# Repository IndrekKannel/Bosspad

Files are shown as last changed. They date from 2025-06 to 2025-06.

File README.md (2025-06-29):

# Bosspad  

I designed a 9 key and 1 encoder macropad for the real bosses. It also has an OLED screen and is designed to be mouted on a vertical surface.  
I plan on using it as a button box for sim racing. 
It uses QMK firmware and supports VIA


## PCB

I designed the PCB with KiCad




## Case

I designed the case in Fusion360 and it can be printed in 2 parts.  
It is assembled with 4 M3x16 screws and 4 M3x5x4mm heatset inserts.



## BOM

### PCB

- 1x Seeed Studio Xiao RP2040
- 1x EC11E Rotary Encoder (switch built in)
- 1x rotary Encoder Knob (can also be printed)
- 1x 0.91" SSD1306 OLED screen
- 9x Cherry MX style switches
- 9x Blank DSA keycaps
- 10x DO-35 diodes (THT)

### Case

- 4x M3x16mm socket head bolts
- 4x M3x5x4mm heatset inserts
- bosspad_top.step
- bosspad_bottom.step

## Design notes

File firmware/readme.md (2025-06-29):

# bosspad

Boss looking macropad

* Keyboard Maintainer: [Indrek Iannel](https://github.com/indrekkannel)
* Hardware Supported: Seeed studio XIAO RP2040
* Hardware Availability: -

See the [build environment setup](https://docs.qmk.fm/#/getting_started_build_tools) and the [make instructions](https://docs.qmk.fm/#/getting_started_make_guide) for more information. Brand new to QMK? Start with our [Complete Newbs Guide](https://docs.qmk.fm/#/newbs).

## Bootloader

Enter the bootloader in 3 ways:

* **Bootmagic reset**: Hold down the key at (0,0) in the matrix (usually the top left key or Escape) and plug in the keyboard
* **Physical reset button**: Briefly press the button on the back of the PCB - some may have pads you must short instead
* **Keycode in layout**: Press the key mapped to `QK_BOOT` if it is available

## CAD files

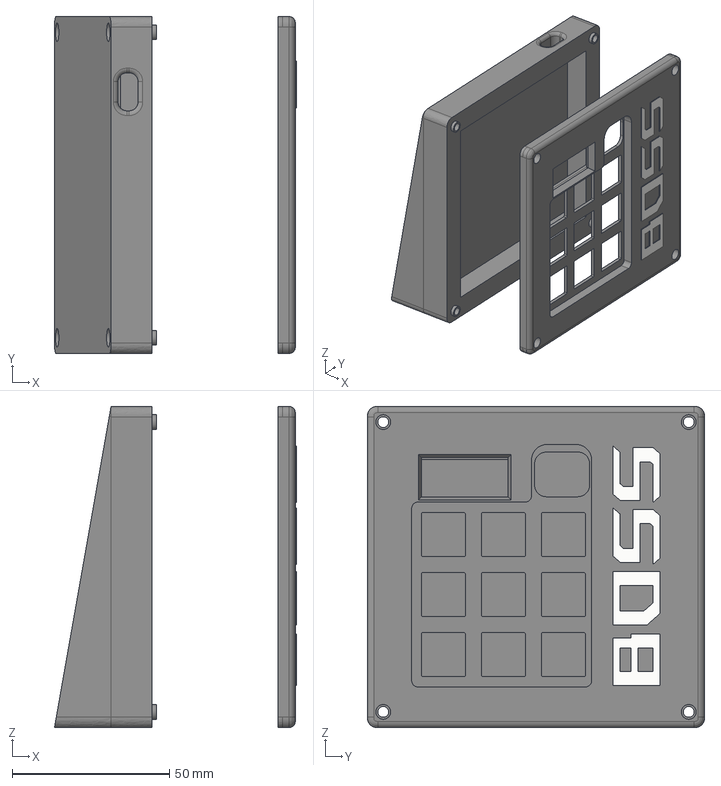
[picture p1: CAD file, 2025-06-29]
cad/bosspad_complete.step
76.9 x 107.0 x 102.0 mm
Macro bottom
macro top

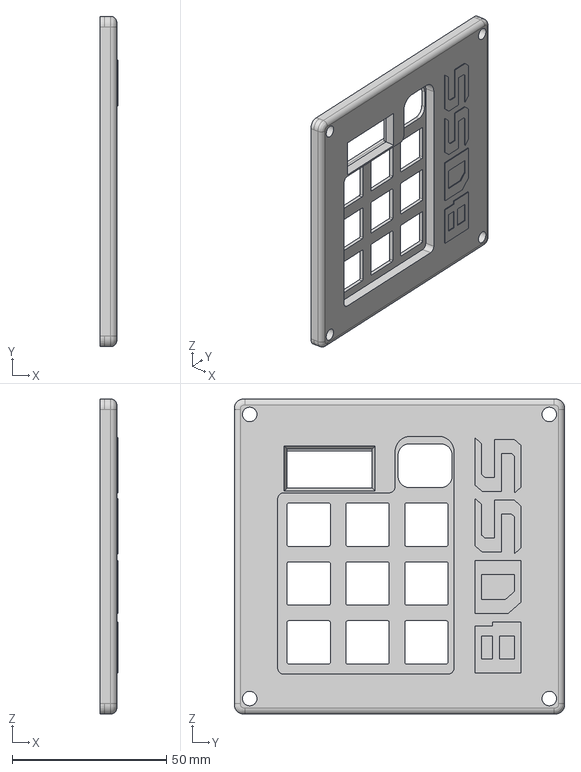
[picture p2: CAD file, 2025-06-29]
production/bosspad_top.step
5.90 x 107.0 x 102.0 mm

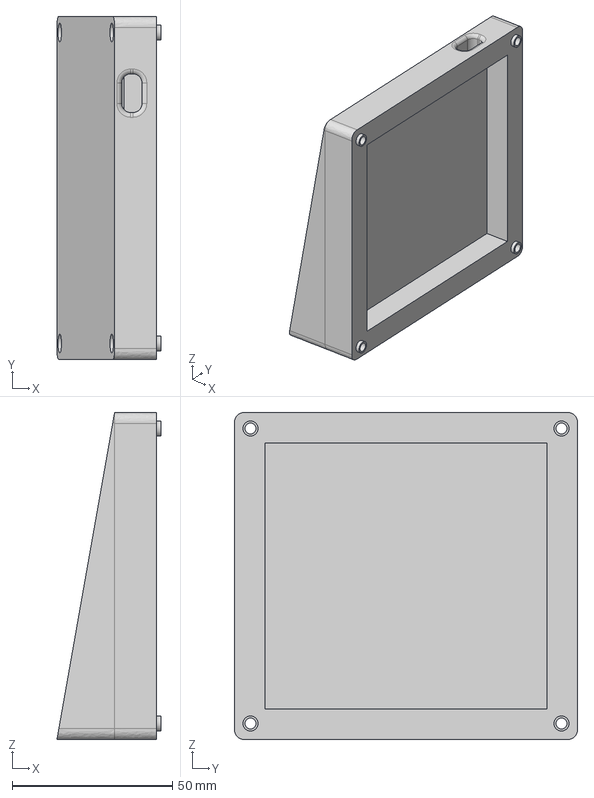
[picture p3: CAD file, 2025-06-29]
cad/bosspad_bottom.step
32.5 x 107.0 x 102.0 mm

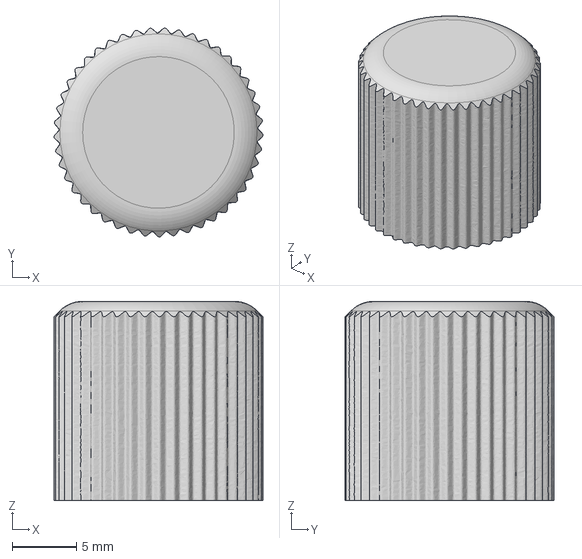
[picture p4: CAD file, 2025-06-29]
production/encoder_knob.step
16.3 x 16.2 x 15.5 mm

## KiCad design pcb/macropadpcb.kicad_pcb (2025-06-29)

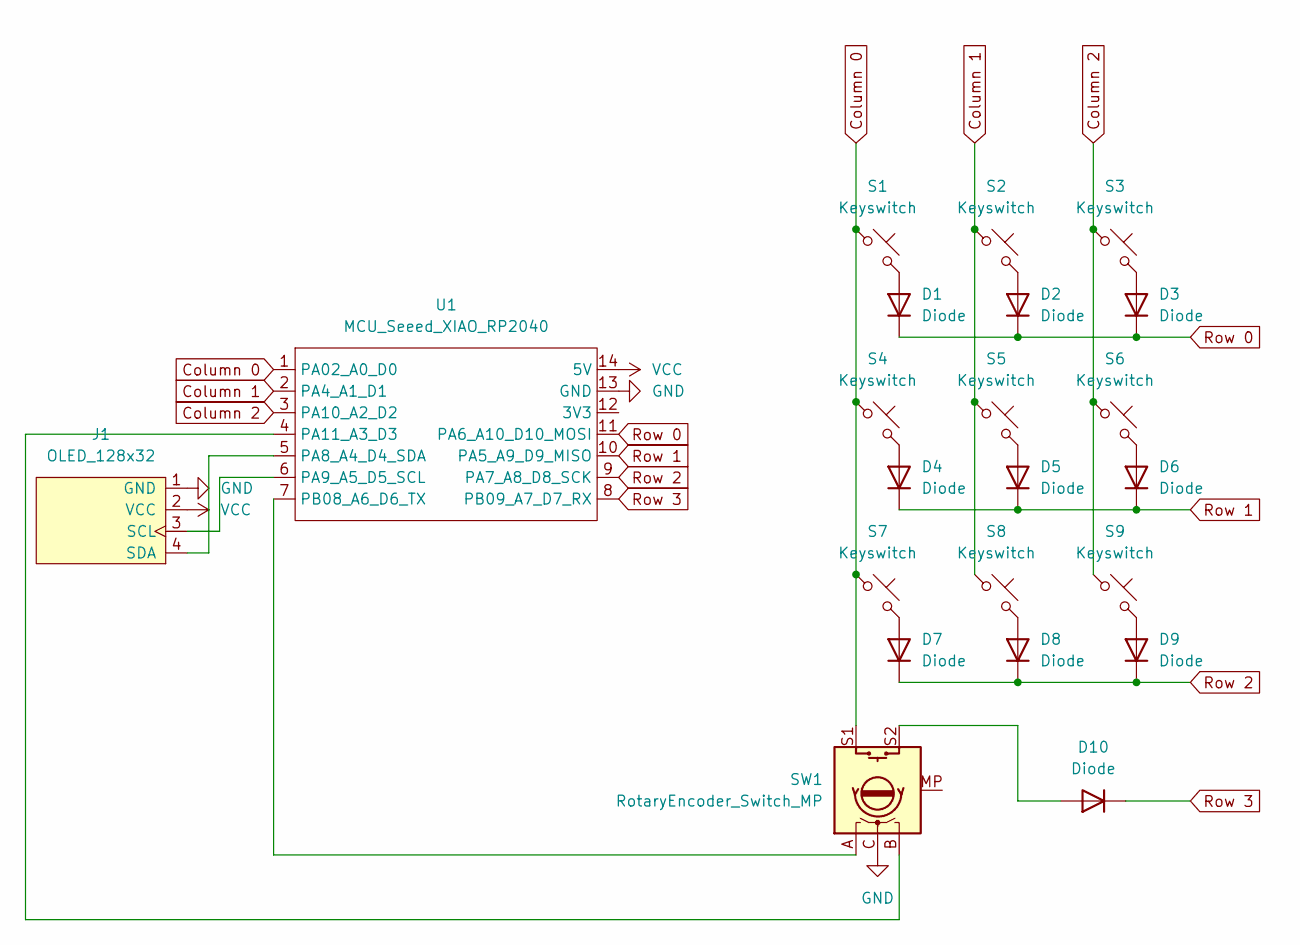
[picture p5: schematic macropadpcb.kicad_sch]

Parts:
D1, D2, D3, D4, D5, D6, D7, D8, D9, D10: Diode; Diode_DO-35
J1: OLED_128x32
S1, S2, S3, S4, S5, S6, S7, S8, S9: Keyswitch; MX_PCB_1.00u
SW1: RotaryEncoder_Switch_MP; RotaryEncoder_Alps_EC11E-Switch_Vertical_H20mm_MountingHoles
U1: MCU_Seeed_XIAO_RP2040; Seeed_XIAO_RP2040

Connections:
Column 0: S1.1, S4.1, S7.1, SW1.S1, U1.1 (PA02_A0_D0)
Column 1: S2.1, S5.1, S8.1, U1.2 (PA4_A1_D1)
Column 2: S3.1, S6.1, S9.1, U1.3 (PA10_A2_D2)
GND: J1.1 (GND), SW1.C, U1.13 (GND)
unnamed: D1.2 (A), S1.2
unnamed: D2.2 (A), S2.2
unnamed: D3.2 (A), S3.2
unnamed: D4.2 (A), S4.2
unnamed: D5.2 (A), S5.2
unnamed: D6.2 (A), S6.2
unnamed: D7.2 (A), S7.2
unnamed: D8.2 (A), S8.2
unnamed: D9.2 (A), S9.2
unnamed: D10.2 (A), SW1.S2
unnamed: J1.3 (SCL), U1.6 (PA9_A5_D5_SCL)
unnamed: J1.4 (SDA), U1.5 (PA8_A4_D4_SDA)
unnamed: SW1.B, U1.4 (PA11_A3_D3)
unnamed: SW1.A, U1.7 (PB08_A6_D6_TX)
Row 0: D1.1 (K), D2.1 (K), D3.1 (K), U1.11 (PA6_A10_D10_MOSI)
Row 1: D4.1 (K), D5.1 (K), D6.1 (K), U1.10 (PA5_A9_D9_MISO)
Row 2: D7.1 (K), D8.1 (K), D9.1 (K), U1.9 (PA7_A8_D8_SCK)
Row 3: D10.1 (K), U1.8 (PB09_A7_D7_RX)
VCC: J1.2 (VCC), U1.14 (5V)

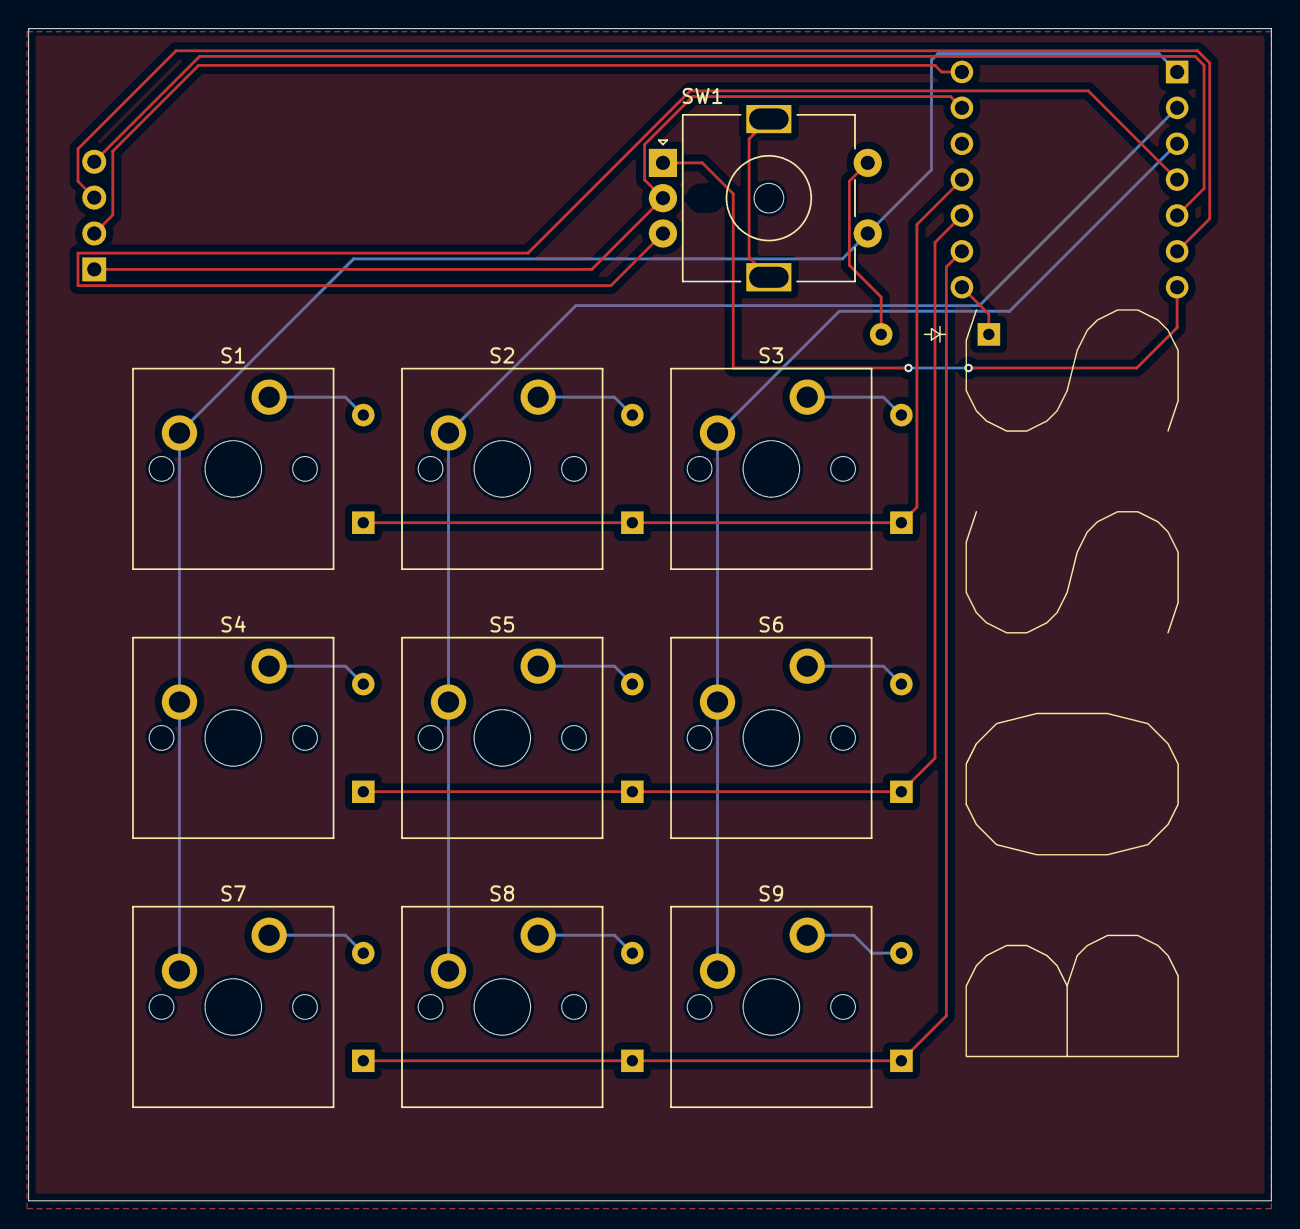
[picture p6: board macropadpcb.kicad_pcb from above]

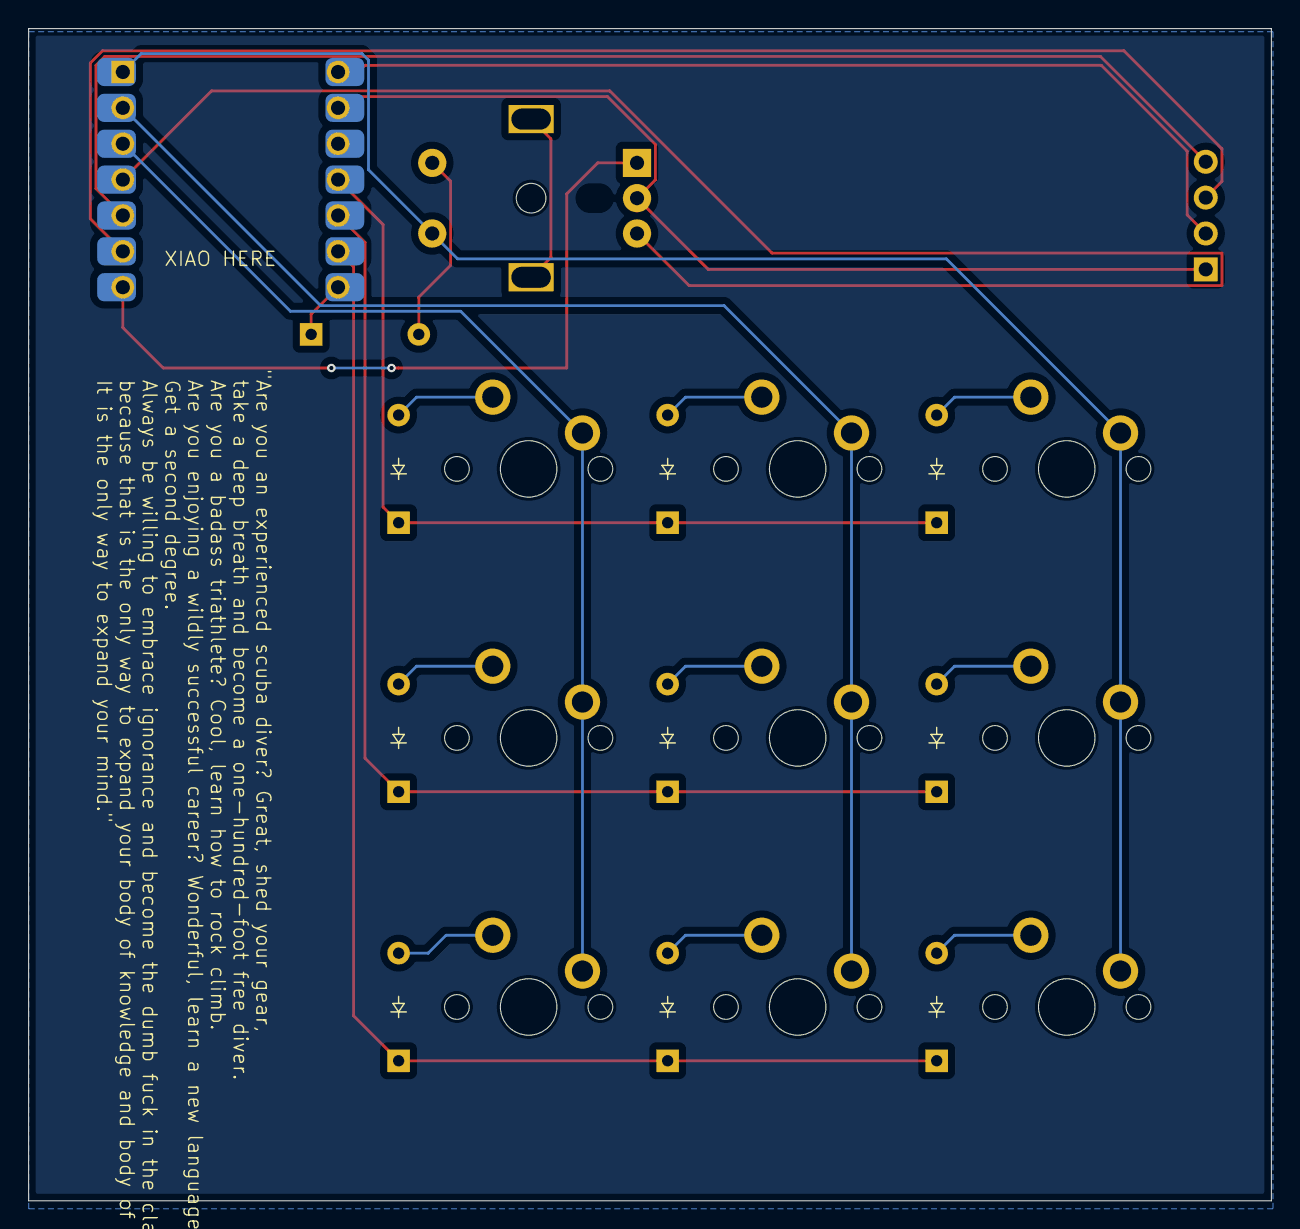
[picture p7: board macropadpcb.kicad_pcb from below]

Board: 2 copper layers, 88.0 x 83.0 mm, 22 parts (10 on the bottom side), 23 nets.

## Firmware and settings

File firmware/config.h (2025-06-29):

#define ENCODER_A_PINS { GP0 }
#define ENCODER_B_PINS { GP29 }
#define NUM_ENCODERS 1
#define I2C_DRIVER I2CD1
#define I2C1_SDA_PIN GP6
#define I2C1_SCL_PIN GP7

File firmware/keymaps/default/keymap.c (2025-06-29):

// Copyright 2023 QMK
// SPDX-License-Identifier: GPL-2.0-or-later

#include QMK_KEYBOARD_H

const uint16_t PROGMEM keymaps[][MATRIX_ROWS][MATRIX_COLS] = {
    /*
     * ┌───┬───┬───┬───┐
     * │ 7 │ 8 │ 9 │ / │
     * ├───┼───┼───┼───┤
     * │ 4 │ 5 │ 6 │ * │
     * ├───┼───┼───┼───┤
     * │ 1 │ 2 │ 3 │ - │
     * ├───┼───┼───┼───┤
     * │ 0 │ . │Ent│ + │
     * └───┴───┴───┴───┘
     */
    [0] = LAYOUT(
        KC_P7,   KC_P8,   KC_P9,   
        KC_P4,   KC_P5,   KC_P6,   
        KC_P1,   KC_P2,   KC_P3,   
        KC_MPLY
    ),
    [1] = LAYOUT(
        KC_P7,   KC_P8,   KC_P9,   
        KC_P4,   KC_P5,   KC_P6,   
        KC_P1,   KC_P2,   KC_P3,   
        KC_MPLY
    ),
    [2] = LAYOUT(
        KC_P7,   KC_P8,   KC_P9,   
        KC_P4,   KC_P5,   KC_P6,   
        KC_P1,   KC_P2,   KC_P3,   
        KC_MPLY
    ),
    [3] = LAYOUT(
        KC_P7,   KC_P8,   KC_P9,   
        KC_P4,   KC_P5,   KC_P6,   
        KC_P1,   KC_P2,   KC_P3,   
        KC_MPLY
    )
};  

const uint16_t PROGMEM encoder_map[][1][2] = {
    [0] = {ENCODER_CCW_CW(KC_VOLD, KC_VOLU)},
    [1] = {ENCODER_CCW_CW(KC_VOLD, KC_VOLU)},
    [2] = {ENCODER_CCW_CW(KC_VOLD, KC_VOLU)},
    [3] = {ENCODER_CCW_CW(KC_VOLD, KC_VOLU)},
};

#ifdef OLED_ENABLE
bool oled_task_user(void) {
    // Host Keyboard Layer Status
    oled_write_P(PSTR("Layer: "), false);

    switch (get_highest_layer(layer_state)) {
        case 0:
            oled_write_P(PSTR("Default\n"), false);
            break;
        case 1:
            oled_write_P(PSTR("1\n"), false);
            break;
        case 2:
            oled_write_P(PSTR("2\n"), false);
            break;
        case 3:
            oled_write_P(PSTR("3\n"), false);
            break;
        default:
            // Or use the write_ln shortcut over adding '\n' to the end of your string
            oled_write_ln_P(PSTR("Undefined"), false);
    }

    return false;
}
#endif
